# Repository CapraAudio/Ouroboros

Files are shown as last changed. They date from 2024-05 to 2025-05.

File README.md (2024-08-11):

# Ouroboros Closed Back Headphones



**Ouroboros** is a closed-back headphone designed for people who value high quality audio. It sports a dark-leaning tuning and a comfortable bass shelf making this headphone sound both fun and high fidelity.<br /> The ring-radiator driver (similar to the one on the legendary HD800 and HD800s) is the reason behind the name **"Ouroboros"**, as when we first laid eyes upon it we were reminded of the serpent eating its tail.<br /> Although the driver is sold as a "coaxial dual driver" speaker, we do not use the small beryllium tweeter as a speaker, instead we de-solder the connections to it and allow it to operate as a passive radiator between the front and rear volumes.

Ouroboros V1 v27

### Intended Frequency Response
graph(61)<br />
[Measurement](https://squig.capraaudio.com/headphones.html?share=Custom_Tilt&bass=0&tilt=-1&treble=0&ear=0)

*If you don't know how to read FR Graphs then check out [this video](https://www.youtube.com/watch?v=f0oWSC6dK4Q) on the basics of how to read and interpret frequency response graphs.

### [Bill of Materials](https://github.com/CapraAudio/Ouroboros/blob/main/Bill-of-Materials.md)

### [Printing Instructions](https://github.com/CapraAudio/Ouroboros/blob/main/Printing-Instructions.md)

### [Assembly Instructions](https://github.com/CapraAudio/Ouroboros/blob/main/Assembly-Instructions.md)

### [Speaker Capsule Files](https://www.printables.com/model/908999-satyr-2-audiophile-open-back-headphones/files)

### [Files for the Headband](https://www.printables.com/model/429232-capra-headband-v2)

### [Support Discord](https://discord.gg/fb4HdDvErF)

This model is set to [Creative Commons - Attribution - Noncommercial - NoDerivatives] because it is designed purposefully, any changes to the design by anyone other than Capra Audio would no longer be the Ouroboros. This includes using the wrong speakers, wrong pads, or missing or wrong front/rear damping materials. The Ouroboros is the complete unit itself. It is hard to design and tune a headphone to be good and we do not want our name associated with a potentially worse version of our design.



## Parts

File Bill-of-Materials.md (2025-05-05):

# The following are Affiliate Links for the specific items and materials required to create the Ouroboros Headphones

* Pads: [Yaxi Pads (Leather)](https://www.amazon.com/dp/B07G5B257L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)

* Speakers: [60mm speaker unit balance,loud field 32ohms 2pcs](https://www.aliexpress.com/item/1005004840197368.html) or [here](https://www.aliexpress.com/item/1005007418230939.html)or [here](https://www.aliexpress.us/item/3256807231916187.html)
<br />**(This listing is known to change, if this link no longer works please contact our support email of support@capraaudio.com)**<br />



* Connectors: [3-Pin Mini-XLR Connectors](https://www.amazon.com/gp/product/B01C3QTS5Q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) or [3.5mm Connectors](https://www.amazon.com/gp/product/B07MN1RK7F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)

* Wire: [22 gauge](https://www.amazon.com/dp/B077XBWX8V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)

* Baffle: [Nylon Mesh (10 Micron)](https://www.amazon.com/Micron-Premium-Press-Blowout-Guarantee/dp/B08X16LVRF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)

* Rear Tuning tape: [3M Micropore Tape](https://www.amazon.com/dp/B000O62TK4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)

* Rear Damping Material [Geekria Tuning Foam](https://www.amazon.com/dp/B07WN8SWHR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)

* Screws: [M3 FHSC Screws recommended kit](https://www.amazon.com/gp/product/B086MC31JT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)

* Brass Inserts: [M3x4x5.7 Brass Heatset inserts](https://amzn.to/4jFsPyi)

Screws required for the speaker housings:

* 10 FHSC M3x12mm
* 12 M3x5mmx5mm Brass Heatset Inserts

Additional Affiliate Links if you want to support us further:
[Polymaker 95a TPU](https://www.amazon.com/gp/product/B09KL2FXNJ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)
[Polymaker PLA Pro](https://www.amazon.com/Polymaker-Filament-1-75mm-Rigidity-Cardboard/dp/B099KS2PDW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)
[Polymaker PETG](https://www.amazon.com/Polymaker-Filament-1-75mm-Strong-Cardboard/dp/B09DKRTSXW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)

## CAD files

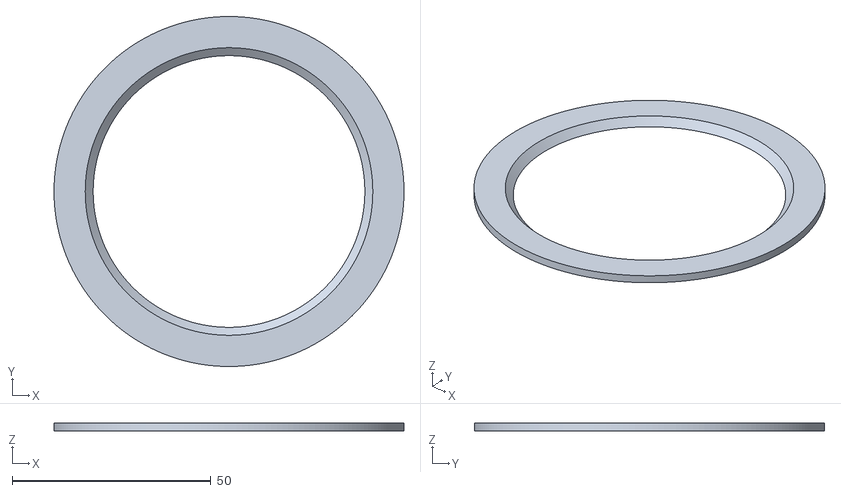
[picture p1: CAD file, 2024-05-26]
Baffle Material Retention Plate{E}.stl
88.0 x 88.0 x 2.00

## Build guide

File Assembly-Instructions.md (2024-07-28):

# NOTICE

It is very important to follow all of these steps to the letter, devating from any of these steps will result in a poorly tuned headphone. If at the end your headphones sound off or wrong give it a few days of listening before you make judgements or try to make changes, if you are used to bad headphones it may take you time to get used to good headphones.

# Or watch [Here](https://youtu.be/O5NK4CFDEhY)

## Prepping the Driver
- Remove the two wires connecting the center speaker to the outer PCB. We arent going to be using that center speaker as a speaker, but instead as a passive radiator.



- Remove the capacitor from the driver as we wont be needing it and it will only get in the way going forward.



- Cut a small piece of the 3M Micropore tape and use 1 layer of it to cover the rear vent on the driver.



- Place the driver into the Driver Mount{C}



## Assembling the Cup

- First Set all 6 of the Brass inserts into the Rear housings{A}, 5 around the rim and one in the tuning port as shown in the picture. (Do not use an insert on the side port if you are using the 3.5mm connector)



## Solder the Wires to the Connectors
# MiniXLR Connectors:
- Solder the wires to the Mini-XLR connector as shown below. (the picture shows you facing the front of the connector)




# 3.5mm Connectors:
- Solder the wires to the 3.5mm connector as shown below.



- I recommend for cable compatibility that you bridge the two negatives by bending the long pin towards the short negative pin as shown below.




## Glue the connectors into the Rear Housing{A}



## Insert the Gasket and Tuning Foam



## Solder the Wires to the Speaker as shown





## Insert the speaker assembly into the gasket



## Place the Grille{D} over the driver



## Cut the 10 micron nylon mesh using the Baffle Material Retention Plate{E} as a guide and place it over the Grille{D}



## Place the Baffle Material Rention Plate{E} over the Grille{D} and the Nylon Mesh



## Place the Pad Mount{F} over the baffle and screw it down with the 5 M3x16 FHSC Screws. Tighten the screws in a star pattern to insure even pressure.



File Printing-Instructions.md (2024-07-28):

# Printing Instructions

The material doesnt matter too much for this asside from the headband which has its own instructions and the Gasket which needs to be printed in 95a TPU.

You'll need a minimum of 3 walls at .4mm wide and 3 top and bottom layers at a minimum of .2mm thick. This has been tested in PLA as well as PETG. ASA is know to have bass resonance issues!

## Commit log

2024-05-26 Added 3D Models
    [Baffle Material Retention Plate{E}.stl, Driver Mount{C}.stl, Gasket{B}.stl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]
2024-06-01 - BoM & README.md: Cleanup
2025-01-20 Update Bill-of-Materials.md
    Added Affiliate Links
